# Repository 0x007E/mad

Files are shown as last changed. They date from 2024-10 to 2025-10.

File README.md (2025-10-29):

  

# `MAD` - Matrix Display



The `MAD` project is based on a pcb with an [ATtiny406/ATtiny1606](#additional-information) and a [Matrix LED Display](#additional-information). It can be used to display data sent over `SPI` or `UART`. The display also implements a small amount of characters from the ASCII table and also has internal space (`EEPROM`) for 16 special characters that can be programmed.

| Experience | Level |
|:---|:-----:|
| Soldering | ?% |
| Mechanical  | ?% |
| Software | ?% |

# Downloads

| Type | File | Description |
|:---:|:---:|:---|
| Schematic | [pdf](https://github.com/0x007E/mad/releases/latest/download/schematic.pdf) / [cadlab](https://cadlab.io/project/28600/main/files) | Schematic files |
| Board | [pdf](https://github.com/0x007E/mad/releases/latest/download/pcb.pdf) / [cadlab](https://cadlab.io/project/28600/main/files) | Board file |
| Drill | [pdf](https://github.com/0x007E/mad/releases/latest/download/drill.pdf) | Drill file |
| PCB | [zip](https://github.com/0x007E/mad/releases/latest/download/kicad.zip) / [tar](https://github.com/0x007E/mad/releases/latest/download/kicad.tar.gz) | KiCAD/Gerber/BoM/Drill files |
| Mechanical | [zip](https://github.com/0x007E/mad/releases/latest/download/freecad.zip) / [tar](https://github.com/0x007E/mad/releases/latest/download/freecad.tar.gz) | FreeCAD/Housing and PCB (STEP) files |
| Firmware | [zip](https://github.com/0x007E/mad/releases/latest/download/firmware.zip) / [tar](https://github.com/0x007E/mad/releases/latest/download/firmware.tar.gz) | Firmware for ATtiny406/ATtiny1606 (Display) |
| Firmware (demo) | [zip](https://github.com/0x007E/mad/releases/latest/download/firmware-demo.zip) / [tar](https://github.com/0x007E/mad/releases/latest/download/firmware-demo.tar.gz) | Test application(s) for ATmega16a |

# Hardware

There are two parts of the hardware. The pcb and the housing of the `MAD`. The pcb is created with [KiCAD](#additional-information) and the housing with `FreeCAD`. The software is programmed with [Microchip (Atmel) Studio](#additional-information). All files are built with `github actions` so that they are ready for a production environment. The housing is printed with a 3D-printer (`Dremel 3D40`).

## PCB

The circuit board is populated on both sides (Top, Bottom). The best way for soldering the `SMD` components is within a vapor phase soldering system and for the `THT` components with a standard soldering system.

### Top Layer

Top Layer

### Bottom Layer

Bottom Layer

## Mechanical

The housing has a tolerance of `0.2mm` on each side of the case. So the pcb should fit perfectly in the housing. The tolerance can be modified with `FreeCAD` in the `Parameter` Spreadsheet.

### Assembled

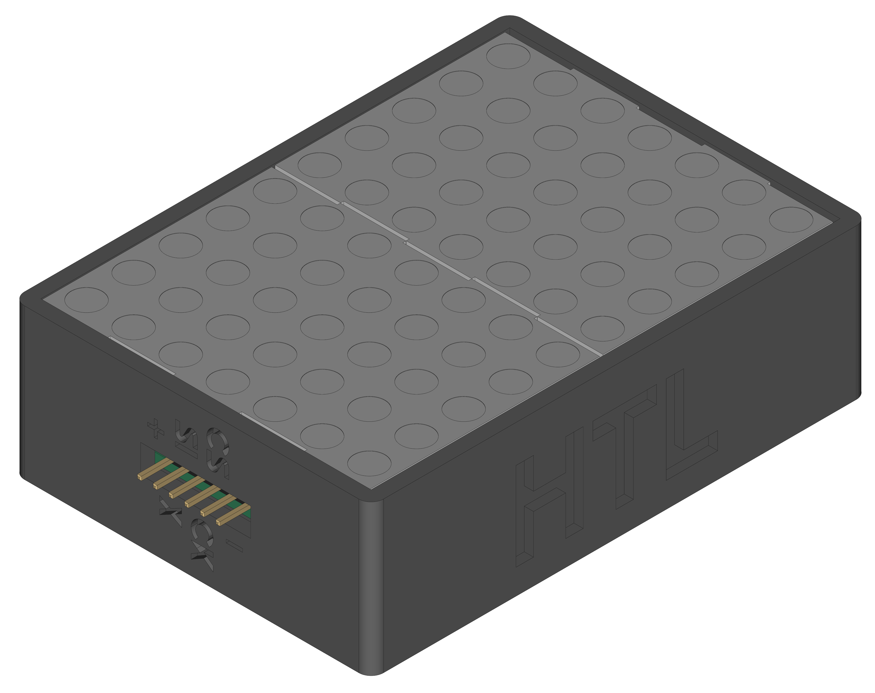
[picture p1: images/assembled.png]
Assembled


#### Exploded

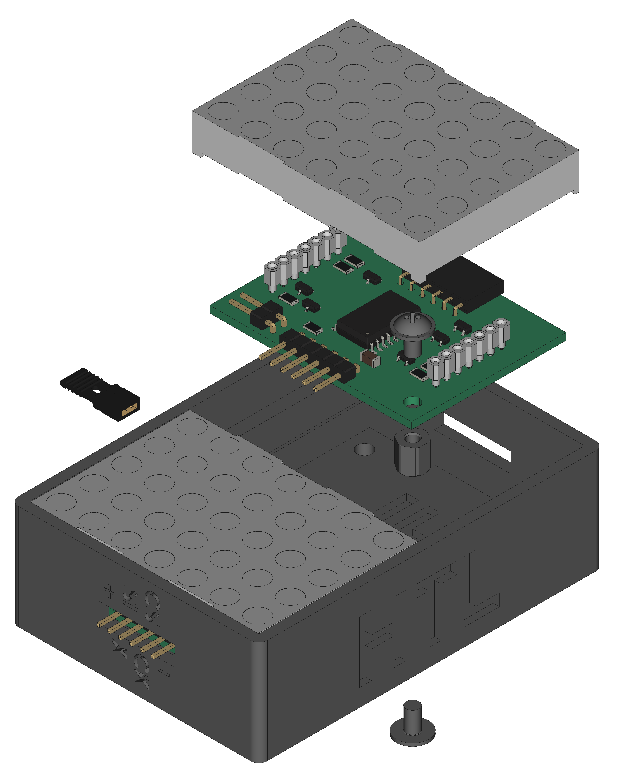
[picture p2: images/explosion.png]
Exploded


# Programming/Setup

The `MAD` is powerd with `5V` from an external source. With Jumper `JP1` bridged the `MAD` can be programmed over [UPDI](#additional-information). To enable `UART` mode the `SS (CS)` Pin must be held low (more details on the [dataflow](#dataflow-diagram) diagram) otherwise the `SPI` mode is enabled. In `UART` mode only one display can be driven. The `SI` pin gets `TXD`and the `SO` pin gets `RXD`. The firmware for the display can be downloaded (see the [download section](#downloads)).

``` bash
#         +-+                                         +----------+      +---------------------+
#        / /                                          |   U  +---+---+  |                     |
#      +-+-+-----------------+                        |   S  |  USB  |--+ +-----------------+ |
#      | JP1                 |                        |   B  +---+---+  | | AVR-Dude        | |
#      |    MAD - Display    |       +---------+      |   /      |      | | ~~~~~~~~        | |
#    +-+-+                 +-+-+   +-+-+  U    |      |   U      |      | | ~~~~~           | |
#    | 1 | VCC         VCC | 1 +---+VCC|  P  +-+-+  +-+-+ A      |      | | ~~~~~~~~~~~~    | |
#    | 2 | UPDI       UPDI | 2 +---+PDI|  D  |GND+--+GND| R      |      | |                 | |
#    | 3 | SI           SO | 3 |   +-+-+  I  |VCC+--+VCC| T      |      | +-----------------+ |
#    | 4 | SCK         SCK | 4 |     |       +---+  +---+ A      |      |                     |
#    | 5 | SS (CS)      SS | 5 +   +-+-+     |RxD+--+RxD| +------+      | Computer            |
#    | 6 | GND         GND | 6 +---+GND|     |TxD+--+TxD| |5V/3V3|      |                     |
#    +-+-+                 +-+-+   +-+-+     +-+-+  +-+-+ +------+      +---------------------+
#      +---------------------+       | ADAPTER |      +----+-----+
#                                    +---------+
```

## FUSES

| Register  | Value  |
|:---:|:---:|
| `WDTCFG`  | `0x00` |
| `BODCFG`  | `0x00` |
| `OSCCFG`  | `0x02` |
| `TCD0CFG` | `0x00` |
| `SYSCFG0` | `0xF5` |
| `SYSCFG1` | `0x00` |
| `APPEND`  | `0x00` |
| `BOOTEND` | `0x00` |

> To setup `SW1` as `RESET` (`PA0`) it is necessary to change the `SYSCFG0`-FUSE of the `ATtiny406/ATtiny1606`. WARNING: To reset the `PA0` pin to `UPDI` mode a `12V` impulse is necessary to program the FUSES again.

# Software

The display software can be controlled by `SPI` or `UART`. The interfaces are displayed in the [dataflow](#dataflow-diagram) diagram. There is a demo software to use the display directly over `spi` (`MAD_Test`) or a `library` (`MAD_LIB`).

## Dataflow diagram

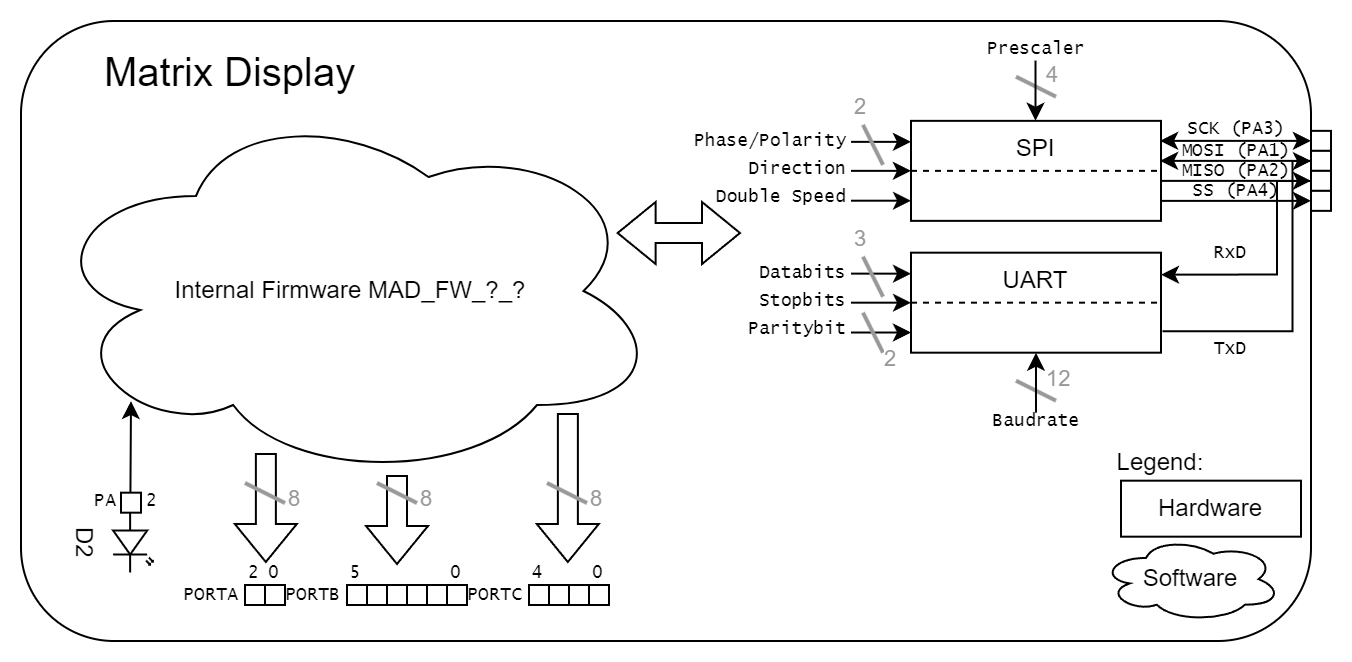
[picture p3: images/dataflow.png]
Dataflow


## UART Test

To send characters to the display over `UART` connect an USB/UART converter to the PC and make a bridge beween `GND` and `SS (CS)` before powering up the display. Start a terminal software on the computer (e.g. [Teraterm](#additional-information)) and setup the following settings:

| Name | Value  |
|:---:|:---:|
| PORT | COM? |
| BAUD | 9600 |
| DATABITS  | 8 |
| PARITY | NONE |
| STOPBITS  | 1 |
| FLOWCTRL  | NONE |

### Connection setup

``` bash

#      +---------------------+                                +---------------------+
#      |    MAD - Display    |                                |                     |
#    +-+-+                 +-+-+                              | +-----------------+ |
#    | 1 | VCC         VCC | 1 +-------+    +----------+      | | TeraTerm        | |
#    | 2 | UPDI       UPDI | 2 |       |    |   U  +---+---+  | | ~~~~~~~~        | |
#    | 3 | SI           SO | 3 +-----+ |    |   S  |  USB  |--+ | ~~~~~           | |
#    | 4 | SCK         SCK | 4 |     | |    |   B  +---+---+  | | ~~~~~~~~~~~~    | |
#    | 5 | SS (CS)      SS | 5 +--+  | |    |   /      |      | |                 | |
# +--+ 6 | GND         GND | 6 +--+  | |    |   U      |      | +-----------------+ |
# |  +-+-+                 +-+-+     | |  +-+-+ A      |      |                     |
# |    +---------------------+       | +--+VCC| R      |      | Computer            |
# |                                  +----+TxD| T      |      |                     |
# |                                       |RxD| +------+      +---------------------+
# +---------------------------------------+GND| |5V/3V3|
#                                         +-+-+ +------+
#                                           +----+-----+
```

## SPI Test

The `firmware` itself contains some demos how to use the display over `spi`. The demo software itself is written for an [ATmega16A](#additional-information). To test the display a connection to the `spi` pins between the display and the [ATmega16A](#additional-information)is necessary.

### Connection setup

``` bash
# ~------------+
# ~          +-+-+
# ~          |VCC+------+
# ~          +-+-+       \        +---------------------+
# ~            |          \       |     MAD - Display   |
# ~  A       +-+-+         \    +-+-+                 +-+-+
# ~  T   [7] | P +- SCK -+  +---+ 1 | VCC         VCC | 1 |
# ~  M       | O |        \     | 2 | UPDI       UPDI | 2 |
# ~  E       | R +- MOSI --\----+ 3 | SI           SO | 3 |
# ~  G       | T +-- SS -+  +---+ 4 | SCK         SCK | 4 |
# ~  A       | B |       +------+ 5 | SS (CS)      SS | 5 |
# ~          |   |           +--+ 6 | GND         GND | 6 |
# ~  1       |   |          /   +-+-+                 +-+-+
# ~  6   [0] |   |         /      |                     |
# ~  A       +-+-+        /       +---------------------+
# ~            |         /
# ~          +-+-+      /
# ~          |GND+-----+
# ~          +-+-+
# ~~~~~~~~~~~~~~ 
```

### SPI Parameter

To control the display through `SPI` the bus of the master needs the following setup:

| Parameter | Value | Description |
|:---|:---:|:---|
| Clock | < 1Mhz  | Bus clock speed should not exceed this value |
| Direction | MSB | MSB needs to be transmitted first |
| Polarity  | Rising  | Polarity of clock is rising `_/` |
| Phase | Rising  | Data is valid when clock is rising `_/` |

> Detail can be found [here](https://de.wikipedia.org/wiki/Serial_Peripheral_Interface)

### SPI Frame

``` bash

# SPI display transmission
# _                                                SS                                                _
#  \________________________________________________________________________________________________/
#                                                 SCK   
#     __    __    __    __    __    __    __    __    __    __    __    __    __    __    __    __    
# ___/1 \__/2 \__/3 \__/4 \__/5 \__/6 \__/7 \__/8 \__/9 \__/10\__/11\__/12\__/13\__/14\__/15\__/16\___
#                                                 MOSI
#    __    __    __    __    __    __    __    __    __    __    __    __    __    __    __    __
# __/C \__/T \__/R \__/L \__/B \__/Y \__/T \__/E \__/D \__/A \__/T \__/A \__/B \__/Y \__/T \__/E \____
#   \__/  \__/  \__/  \__/  \__/  \__/  \__/  \__/  \__/  \__/  \__/  \__/  \__/  \__/  \__/  \__/
#    [7                   :                    0]    [7                   :                    0]
```

### SPI Commands

To enable a bit it needs to be set to on ($1=ON$). To disable a bit it is necessary to set it to off ($0=OFF$).

| Control-Byte | Data-Bit(s)| Description |
|:---:|:---:|:---|
| `0x00` | `0xXX` | No operation | 
| `0x01` | `[4:0]` | ROW1 LEDs | 
| ... | ... | ... | 
| `0x07` | `[4:0]` | ROW7 LEDs | 
| `0x08` | `[6:0]` | Show ASCII character on display |
| `0x10` | `0xXX` | Clear buffer |
| `0x1F` | `[0]` | Enable display |
| `0x20` | `0xXX` | Copy EEPROM address (0) to display |
| ... | ... | ... | 
| `0x2F` | `0xXX` | Copy EEPROM address (15) to display |
| `0x30` | `0xXX` | Copy Display content to EEPROM address (0) |
| ... | ... | ... | 
| `0x3F` | `0xXX` | Copy Display content to EEPROM address (15) |
| `0xF0` | `0xXX` | Display refresh rate LOW byte |
| `0xF1` | `0xXX` | Display refresh rate HIGH byte |
| `0xFF` | `0xXX` | RESET the SPI queue |

### Example Library (`matrix.h`)

With the attached demo library (`MAD_LIB`) it is quiet easy to use the display. To setup the matrix display library some `defines` needs to be adjusted.

``` c
// Setup the number of displays that are cascaded
#ifndef MATRIX_DISPLAYS
    #define MATRIX_DISPLAYS 2
#endif
```

``` c
#include "../lib/matrix/matrix.h"

int main(void)
{
    matrix_init();
    matrix_reset();
    _delay_ms(MATRIX_RESET_RECOVERY_TIME_MS);
    matrix_enable();

    matrix_char(1, 'A');
    _delay_ms(1000);
    matrix_char(2, 'B');

    matrix_frame(buffer);
    // ...
}
```

# Additional Information

| Type | Link | Description |
|:---:|:---:|:---|
| ATtiny406  | [pdf](https://ww1.microchip.com/downloads/en/DeviceDoc/Microchip%208bit%20mcu%20AVR%20ATtiny406%20data%20sheet%2040001976A.pdf) | ATtiny microcontroller |
| ATtiny1606 | [pdf](http://ww1.microchip.com/downloads/en/DeviceDoc/ATtiny806_1606_Data_Sheet_40002029A.pdf) | ATtiny microcontroller |
| ATmega16A | [pdf](https://ww1.microchip.com/downloads/en/devicedoc/atmel-8154-8-bit-avr-atmega16a_datasheet.pdf) | Microchip ATmega16A Datasheet |
| TA20-11SRWA | [pdf](https://www.kingbrightusa.com/images/catalog/spec/ta20-11srwa.pdf) | Dot Matrix Dispaly |
| Atmel ICE | [pdf](https://ww1.microchip.com/downloads/en/DeviceDoc/Atmel-ICE_UserGuide.pdf) | Atmel ICE datasheet |
| UPDI | [web](https://github.com/0x007e/updi) | UPDI-Adapter with AVR-Dude |
| Microchip Studio | [web](https://www.microchip.com/en-us/tools-resources/develop/microchip-studio) | Download page for Microchip Studio |
| KiCAD | [web](https://www.kicad.org/) | KiCAD project page |
| FreeCAD | [web](https://www.freecad.org/) | FreeCAD project page |
| TeraTerm | [web](https://github.com/TeraTermProject/teraterm/releases/download/v5.3/teraterm-5.3.zip) | Terminal software for UART |

---

R. GAECHTER

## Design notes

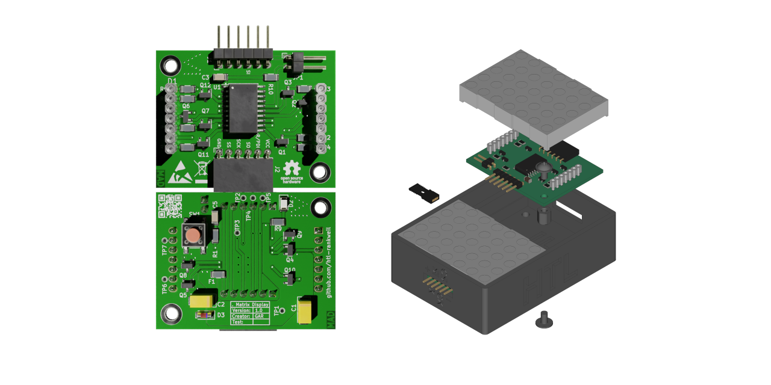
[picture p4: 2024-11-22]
images/social.png

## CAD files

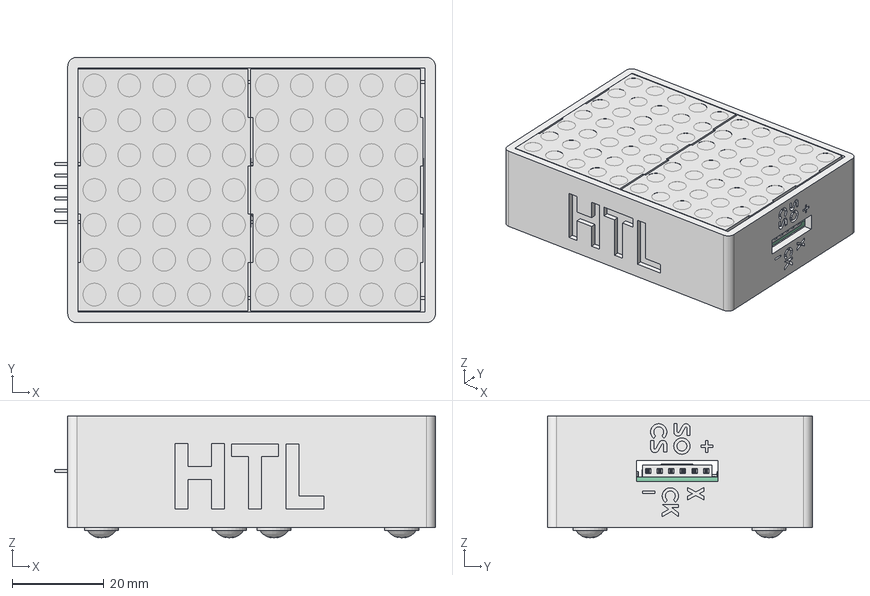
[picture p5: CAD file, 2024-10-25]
mechanical/housing.FCStd
83.3 x 58.0 x 26.6 mm
Pcb_6941
R2_R_1206_3216Metric_98e40b51c5ca
D1_TX20_12e11b00d063
C3_C_1206_3216Metric_6d504ac9ac06
U1_SOIC_20W_75x128mm_P127mm_c0145f4def36
Q1_SOT_23_cf4c01585177
Q1_SOT_23_cf4c01585178
Q1_SOT_23_cf4c01585179
J1_PinHeader_1x06_P254mm_Horizontal_252ccb66f138
JP1_PinHeader_1x02_P254mm_Horizontal_312941c267f2
R2_R_1206_3216Metric_98e40b51c5ca001
R2_R_1206_3216Metric_98e40b51c5ca002
Q1_SOT_23_cf4c01585180
R2_R_1206_3216Metric_98e40b51c5ca003
Q1_SOT_23_cf4c01585181
Q1_SOT_23_cf4c01585182
Q1_SOT_23_cf4c01585183
J2_PinSocket_1x06_P254mm_Horizontal_fd336a903c1f
R2_R_1206_3216Metric_98e40b51c5ca004
R2_R_1206_3216Metric_98e40b51c5ca005
R2_R_1206_3216Metric_98e40b51c5ca006
R2_R_1206_3216Metric_98e40b51c5ca007
Q1_SOT_23_cf4c01585184
R2_R_1206_3216Metric_98e40b51c5ca008
Q1_SOT_23_cf4c01585185
F1_Fuse_1206_3216Metric_63008e3cc08f
C2_CP_EIA_6032_28_Kemet_C_cdabaab988ab
Q1_SOT_23_cf4c01585186
C2_CP_EIA_6032_28_Kemet_C_cdabaab988ab001
SW1_SW_SPST_PTS645_049d22935f3d
Q1_SOT_23_cf4c01585187
C3_C_1206_3216Metric_6d504ac9ac007
R2_R_1206_3216Metric_98e40b51c5ca009
Q1_SOT_23_cf4c01585188
D2_LED_1206_3216Metric_d163399e3e38
D3_D_MiniMELF_Standard_883c4249edc9
Pcb_6942
R2_R_1206_3216Metric_98e40b51c5ca010
D1_TX20_12e11b00d064
C3_C_1206_3216Metric_6d504ac9ac008
U1_SOIC_20W_75x128mm_P127mm_c0145f4def037
Q1_SOT_23_cf4c01585189
Q1_SOT_23_cf4c01585190
Q1_SOT_23_cf4c01585191
J1_PinHeader_1x06_P254mm_Horizontal_252ccb66f139
JP1_PinHeader_1x02_P254mm_Horizontal_312941c267f003
R2_R_1206_3216Metric_98e40b51c5ca011
R2_R_1206_3216Metric_98e40b51c5ca012
Q1_SOT_23_cf4c01585192
R2_R_1206_3216Metric_98e40b51c5ca013
Q1_SOT_23_cf4c01585193
Q1_SOT_23_cf4c01585194
Q1_SOT_23_cf4c01585195
J2_PinSocket_1x06_P254mm_Horizontal_fd336a903c1f001
R2_R_1206_3216Metric_98e40b51c5ca014
R2_R_1206_3216Metric_98e40b51c5ca015
R2_R_1206_3216Metric_98e40b51c5ca016
R2_R_1206_3216Metric_98e40b51c5ca017
Q1_SOT_23_cf4c01585196
R2_R_1206_3216Metric_98e40b51c5ca018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

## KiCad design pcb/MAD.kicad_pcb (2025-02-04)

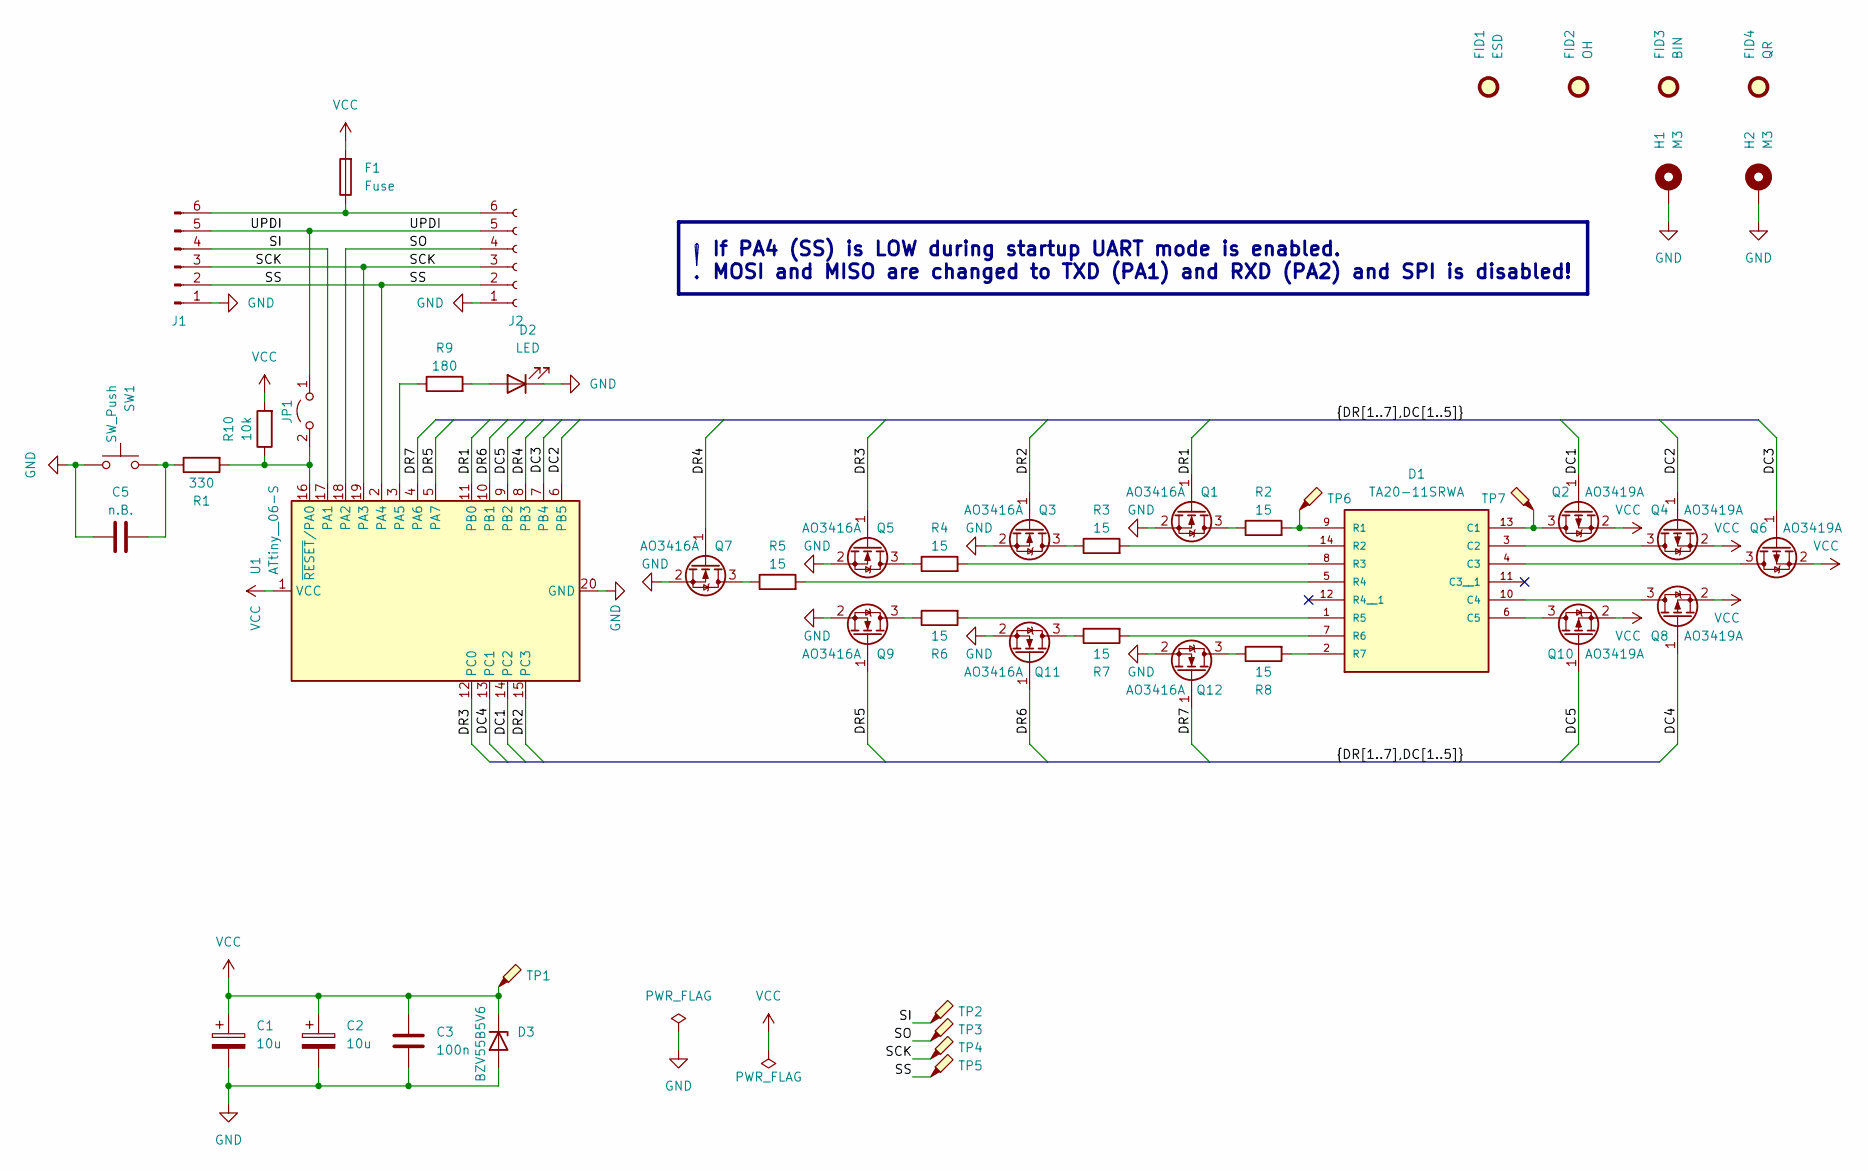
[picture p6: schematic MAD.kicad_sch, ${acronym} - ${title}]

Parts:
C1, C2: 10u; CP_EIA-6032-28_Kemet-C
C3: 100n; C_1206_3216Metric
C5: n.B.; C_1206_3216Metric
D1: TA20-11SRWA; LED_TA20-11SRWA
D2: LED; LED_1206_3216Metric
D3: BZV55B5V6; D_MiniMELF
F1: Fuse; Fuse_1206_3216Metric
FID1: ESD; ESD-Logo_6.6x6mm_SilkScreen
FID2: OH; OSHW-Logo_5.7x6mm_SilkScreen
FID3: BIN; WEEE-Logo_4.2x6mm_SilkScreen
FID4: QR; QR_0x007e
H1, H2: M3; MountingHole_3.2mm_M3_DIN965_Pad
J1: Conn_01x06_Pin; PinHeader_1x06_P2.54mm_Horizontal
J2: Conn_01x06_Socket; PinSocket_1x06_P2.54mm_Horizontal
JP1: Jumper_2_Open; PinHeader_1x02_P2.54mm_Horizontal
Q1, Q3, Q5, Q7, Q9, Q11, Q12: AO3416A; SOT-23
Q2, Q4, Q6, Q8, Q10: AO3419A; SOT-23
R1: 330; R_1206_3216Metric
R2, R3, R4, R5, R6, R7, R8: 15; R_1206_3216Metric
R9: 180; R_1206_3216Metric
R10: 10k; R_1206_3216Metric
SW1: SW_Push; SW_SPST_PTS645
TP1, TP2, TP3, TP4, TP5, TP6, TP7: TestPoint_Probe; TestPoint_Pad_D1.0mm
U1: ATtiny__06-S; SOIC-20W_7.5x12.8mm_P1.27mm

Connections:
/DC1: Q2.1 (G), U1.14 (PC2)
/DC2: Q4.1 (G), U1.6 (PB5)
/DC3: Q6.1 (G), U1.7 (PB4)
/DC4: Q8.1 (G), U1.13 (PC1)
/DC5: Q10.1 (G), U1.9 (PB2)
/DR1: Q1.1 (G), U1.11 (PB0)
/DR2: Q3.1 (G), U1.15 (PC3)
/DR3: Q5.1 (G), U1.12 (PC0)
/DR4: Q7.1 (G), U1.8 (PB3)
/DR5: Q9.1 (G), U1.5 (PA7)
/DR6: Q11.1 (G), U1.10 (PB1)
/DR7: Q12.1 (G), U1.4 (PA6)
/SCK: J1.3, J2.3, TP4.1, U1.19 (PA3)
/SI: J1.4, TP2.1, U1.17 (PA1)
/SO: J2.4, TP3.1, U1.18 (PA2)
/SS: J1.2, J2.2, TP5.1, U1.2 (PA4)
/UPDI: J1.5, J2.5, JP1.1 (A)
GND: C1.2, C2.2, C3.2, C5.2, D2.1 (K), D3.2 (A), H1.1, H2.1, J1.1, J2.1, Q1.2 (S), Q3.2 (S), Q5.2 (S), Q7.2 (S), Q9.2 (S), Q11.2 (S), Q12.2 (S), SW1.1, U1.20 (GND)
unnamed: C5.1, R1.1, SW1.2
unnamed: D1.13 (C1), Q2.3 (D), TP7.1
unnamed: D1.3 (C2), Q4.3 (D)
unnamed: D1.4 (C3), Q6.3 (D)
unnamed: D1.10 (C4), Q8.3 (D)
unnamed: D1.6 (C5), Q10.3 (D)
unnamed: D1.9 (R1), R2.2, TP6.1
unnamed: D1.14 (R2), R3.2
unnamed: D1.8 (R3), R4.2
unnamed: D1.5 (R4), R5.2
unnamed: D1.1 (R5), R6.2
unnamed: D1.7 (R6), R7.2
unnamed: D1.2 (R7), R8.2
unnamed: D2.2 (A), R9.2
unnamed: F1.1, J1.6, J2.6
unnamed: JP1.2 (B), R1.2, R10.1, U1.16 (~RESET/PA0)
unnamed: Q1.3 (D), R2.1
unnamed: Q3.3 (D), R3.1
unnamed: Q5.3 (D), R4.1
unnamed: Q7.3 (D), R5.1
unnamed: Q9.3 (D), R6.1
unnamed: Q11.3 (D), R7.1
unnamed: Q12.3 (D), R8.1
unnamed: R9.1, U1.3 (PA5)
VCC: C1.1, C2.1, C3.1, D3.1 (K), F1.2, Q2.2 (S), Q4.2 (S), Q6.2 (S), Q8.2 (S), Q10.2 (S), R10.2, TP1.1, U1.1 (VCC)

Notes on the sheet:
If PA4 (SS) is LOW during startup UART mode is enabled. MOSI and MISO are changed to TXD (PA1) and RXD (PA2) and SPI is disabled!

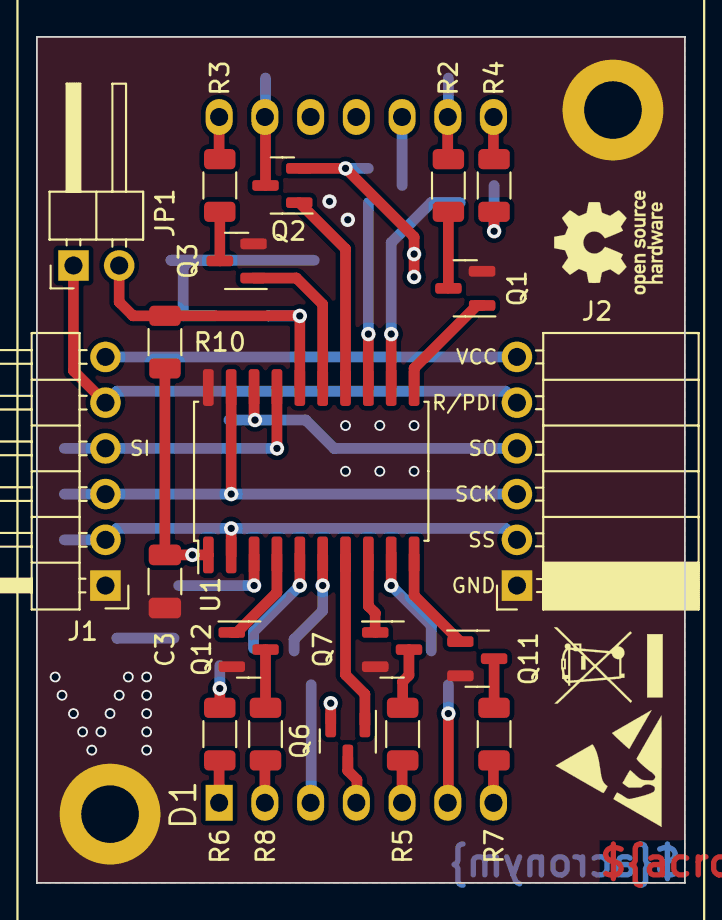
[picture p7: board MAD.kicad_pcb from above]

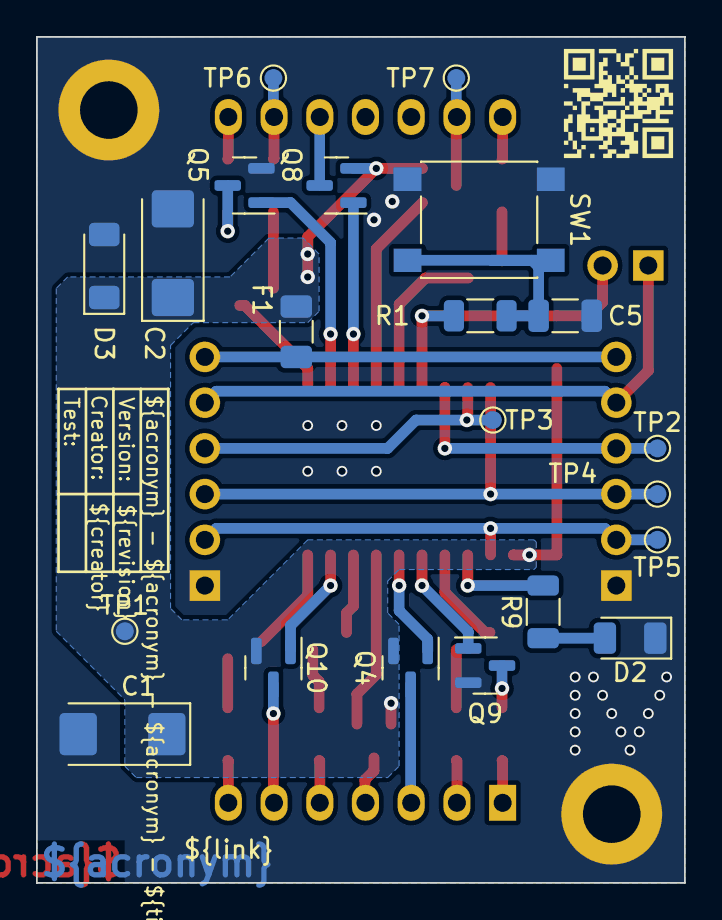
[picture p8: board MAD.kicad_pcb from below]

Board: 2 copper layers, 36.0 x 47.0 mm, 48 parts (22 on the bottom side), 43 nets.

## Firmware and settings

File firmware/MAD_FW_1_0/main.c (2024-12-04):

/* -----------------------------------------
* G.Raf^engineering
* www.sunriax.at
* -----------------------------------------
*    Platform: .matrix display controller
*    Hardware: ATTiny406/1606/...
* -----------------------------------------
*     Version: 1.0 Release
*      Author: G.Raf
* Description:
*   .matrix display controller firmware
* -----------------------------------------
*/

#define F_CPU 20000000UL

// Uncomment to disable signal led
#define SIGNAL_LED PIN5_bm

#define BAUDRATE 9600UL
#define UART_INIT_WAIT_MS 1000UL
// #define USE_U2X

#include <avr/io.h>
#include <avr/cpufunc.h>
#include <avr/interrupt.h>
#include <util/delay.h>

#include "./system/system.h"
#include "./matrix/matrix.h"

#ifdef USE_U2X
    #define USART0_BAUD_RATE(BAUD_RATE) ((float)(CLK_PER * 64 / (8 * (float)BAUD_RATE)) + 0.5)
#else
    #define USART0_BAUD_RATE(BAUD_RATE) ((float)(CLK_PER * 64 / (16 * (float)BAUD_RATE)) + 0.5)
#endif

ISR(SPI0_INT_vect)
{
    sei();	// Allow nested interrupts
    SPI0.DATA = matrix_queue(SPI0.DATA);
    SPI0.INTFLAGS = SPI_IF_bm;
}

ISR(USART0_RXC_vect)
{
    sei();	// Allow nested interrupts
    
    matrix_queue(0x08);
    matrix_queue(USART0.RXDATAL);
    matrix_execute();
    
    // DATA transfer LED
#ifdef SIGNAL_LED
    PORTA.OUTTGL = SIGNAL_LED;
#endif
    USART0.STATUS = USART_RXCIF_bm;
}

ISR(PORTA_PORT_vect)
{
    sei();	// Allow nested interrupts

    // DATA transfer LED
#ifdef SIGNAL_LED
    PORTA.OUTTGL = SIGNAL_LED;
#endif

    matrix_execute();

    PORTA.INTFLAGS = PIN4_bm;
}

ISR(TCA0_OVF_vect)
{
    matrix_refresh();

    TCA0.SINGLE.INTFLAGS = TCA_SINGLE_OVF_bm;
}

int main(void)
{
    system_init();

    // PORT Setup
    PORTA.DIRCLR = PIN4_bm;				// Set SS to input
    PORTA.PIN4CTRL = PORT_PULLUPEN_bm;	// Enable pullup on SS
    
    // DATA transfer LED
#ifdef SIGNAL_LED
    PORTA.DIRSET = SIGNAL_LED;          // Enable signal LED
#endif

    // DISPLAY Update
    matrix_setup();

    // Enable interrupts globally
    sei();

    matrix_test();

    // UART Setup
    if(!(PORTA.IN & PIN4_bm))
    {
        // DATA transfer LED
#ifdef SIGNAL_LED
        PORTA.OUTSET = SIGNAL_LED;
#endif
        _delay_ms(UART_INIT_WAIT_MS);

        PORTMUX.CTRLB = PORTMUX_USART0_ALTERNATE_gc;
        
        USART0.BAUD = (unsigned int)USART0_BAUD_RATE(BAUDRATE);
        USART0.CTRLA = USART_RXCIE_bm;
        USART0.CTRLB = USART_RXEN_bm;
        
        #if USE_U2X
        USART0.CTRLB |= USART_RXMODE_CLK2X_gc;
        #endif

        MATRIX_ENABLE();
    }
    //SPI Setup
    else
    {
        PORTA.DIR &= ~PIN1_bm;	// Set MOSI to input
        PORTA.DIR |= PIN2_bm;	// Set MISO to output
        PORTA.DIR &= ~PIN3_bm;	// Set SCK to input
        
        PORTA.PIN4CTRL |= PORT_ISC_RISING_gc;
        
        SPI0.CTRLA = SPI_ENABLE_bm;
        SPI0.INTCTRL = SPI_IE_bm;
    }
    
    while (1)
    {
        matrix_ascii_read();
        matrix_eeprom_read();
        matrix_eeprom_write();
    }
}

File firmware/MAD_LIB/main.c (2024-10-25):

#define F_CPU 12000000UL
//#define WRITE_EEPROM

#include <avr/io.h>
#include <util/delay.h>

#include "../lib/matrix/matrix.h"

unsigned char buffer[(MATRIX_DISPLAYS * MATRIX_ROWS)];

int main(void)
{
    matrix_init();
    matrix_reset();
    _delay_ms(MATRIX_RESET_RECOVERY_TIME_MS);

    matrix_enable();

    #ifdef WRITE_EEPROM

    unsigned char temp[] = {
        0b00000001,
        0b00000011,
        0b00000111,
        0b00001111,
        0b00000111,
        0b00000011,
        0b00000001
    };

    matrix_buffer2eeprom(1, 0, temp);
    matrix_buffer2eeprom(2, 0, temp);

    temp[0] = 0b00010000;
    temp[1] = 0b00011000;
    temp[2] = 0b00011100;
    temp[3] = 0b00011110;
    temp[4] = 0b00011100;
    temp[5] = 0b00011000;
    temp[6] = 0b00010000;

    matrix_buffer2eeprom(1, 1, temp);
    matrix_buffer2eeprom(2, 1, temp);

    #endif

    unsigned char i=1;

    for (unsigned char y=0; y < (MATRIX_DISPLAYS * MATRIX_ROWS); y++)
    {

        for (unsigned char x=0; x < MATRIX_COLUMNS; x++)
        {
            if(i <= x)
            {
                break;
            }
            buffer[y] |= (1<<(i - 1));
        }

        if((++i) > MATRIX_COLUMNS)
        {
            i = 1;
        }
    }
    matrix_frame(buffer);
    _delay_ms(2000);

    unsigned int display_refresh_rate = MATRIX_STANDARD_DISPLAY_REFRESH_RATE;

    PORTA |= 0x0F;

    while (1)
    {
        matrix_char(1, 'A');
        _delay_ms(1000);
        matrix_char(2, 'B');
        _delay_ms(1000);
        matrix_clear(1);
        _delay_ms(1000);
        matrix_clear(2);
        _delay_ms(1000);
        matrix_char(1, 'A');
        _delay_ms(1000);
        matrix_char(2, 'B');
        _delay_ms(1000);
        matrix_clear_all();
        _delay_ms(1000);
        matrix_eeprom2buffer(1, 0);
        matrix_eeprom2buffer(2, 1);
        _delay_ms(1000);
        matrix_eeprom2buffer(1, 1);
        matrix_eeprom2buffer(2, 0);
        _delay_ms(1000);

        if(!(PINA & 0x01))
        {
            display_refresh_rate -= 100UL;
            matrix_display_refresh(1, display_refresh_rate);
        }
        else if(!(PINA & 0x02))
        {
            display_refresh_rate += 100UL;
            matrix_display_refresh(1, display_refresh_rate);
        }
    }
}

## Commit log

2024-10-25 Fix wrong device
2024-10-25 Fix pin name
2024-11-22 Optimize resistor values
    [MAD.kicad_pcb, MAD.kicad_sch]
2024-11-22 Rearrange fabrication text
    [MAD.kicad_pcb]
2024-11-22 Change SPI-Bus names
    [MAD.kicad_pcb, MAD.kicad_sch]
2024-11-22 Add ATtiny __06 to design
    [MAD.kicad_pcb, MAD.kicad_sch]
2024-11-22 Rename SPI-Bus names
2024-11-22 Add missing SPI-Command
2024-11-22 Fix SPI direction
2024-11-25 Fix number in partlist
    [MAD.kicad_pcb, MAD.kicad_sch]
2024-11-27 Add mounting screw
    [MAD.kicad_pcb, MAD.kicad_sch]
2024-11-29 Change SPI speed
2024-12-01 Activate signaling LED
2024-12-02 Fix UART
2024-12-02 Change UART connection setup
2024-12-04 Add option to disable status led
2024-12-06 Optimize current consumption
    [MAD.kicad_pcb, MAD.kicad_sch]
2025-02-04 Activate TA20 in 3D-View
    [MAD.kicad_pcb]
2025-02-04 Add housing to artifacts
2025-03-26 Pull SS HIGH to prevent UART mode

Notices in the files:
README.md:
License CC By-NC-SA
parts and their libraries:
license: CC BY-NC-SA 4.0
